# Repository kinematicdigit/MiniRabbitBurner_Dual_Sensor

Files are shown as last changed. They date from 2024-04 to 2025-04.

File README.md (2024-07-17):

# MiniRabbitBurner_Dual_Sensor (remixed Mini Stealthburner with Dual Sensors)

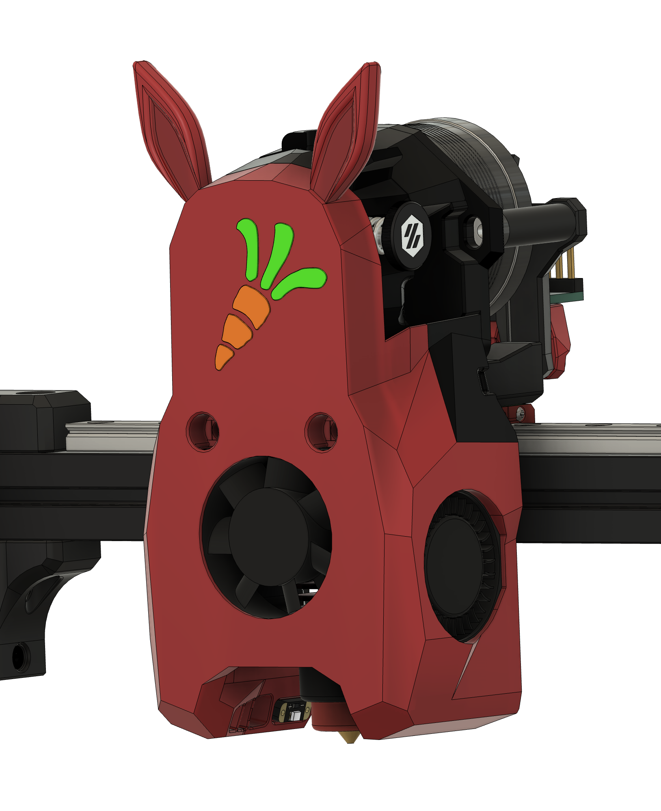
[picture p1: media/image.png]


Remix and optimized the Mini Stealthburner with dual sensors for use with ERCF. The filament path has been optimized for heavy load and unload duty cycles. Redesigned filament path for a more stable structure to handle the loading of heavily curved filaments and new wire channels for managing the new sensor wires.

BOM (in addition to standard Mini Stealthburner BOM)
(2)x Omron D2F-5L, D2F-01F, or D2F-01L Micro Switch
(1)x MR85ZZ bearings
(1)x 5.5 steel ball
(3) coloured 28AWG wires
(2)x M2x10mm SHCS or BHCS
(2) interconnects for your breakout board
(2) LED Sequins (optional)

Requires some soldering and well-tuned printer. Print the Swiss cheese calibration cube included in the repo.

Remixed/inspired from single switch version from:

https://www.printables.com/model/562384-voron-mini-stealthburner-ercf-filament-sensor

Redesigned from the original at:

https://github.com/VoronDesign/Voron-0/tree/Voron0.2r1/STLs

Added klicky mount versions based on:

https://github.com/jlas1/Klicky-Probe/blob/main/Printers/Voron/v0/v0_STL/V0_2r1_Klicky_MiniSB_Cowling.stl

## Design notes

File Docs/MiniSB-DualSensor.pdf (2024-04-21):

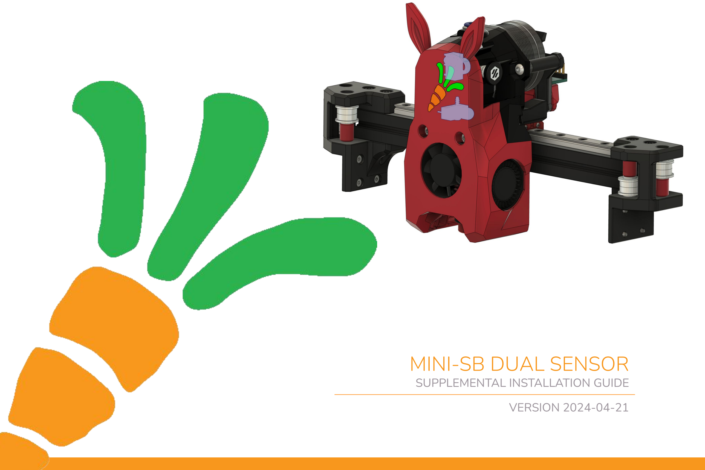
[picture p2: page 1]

VERSION 2024-04-21

# MINI-SB DUAL SENSOR

SUPPLEMENTAL INSTALLATION GUIDE

MINI STEALTHBURNER - DUAL SENSOR EDITION

2

This is a remix and optimized Mini Stealthburner with dual sensors for use with ERCF. The filament path has been optimized for heavy load and unload duty cycles. Redesigned filament path for a more stable structure to handle the loading of heavily curved filaments and new wire channels for managing the new sensor wires.
BOM (in addition to standard Mini Stealthburner BOM)
(2)x Omron D2F-5L, D2F-01F, or D2F-01L Micro Switch
(1)x MR85ZZ bearings
(1)x 5.5 steel ball (3) coloured 28AWG wires
(2)x M2x10mm SHCS or BHCS
(2) interconnects for your breakout board

Requires some soldering and well-tuned printer. Print the Swiss cheese calibration cube included in the repo. Please refer to the original Mini Stealthburner guide found in the Doc folder of the GitHub repository. I did not include every toolhead from the original repository, but if you are looking for a specific one, please request it and I can make an adjustment for it. I included the most popular heads in this current edition.

Remixed/inspired from single switch version from: https://www.printables.com/model/562384-voron-mini-stealthburner-ercf-filament-sensor

Redesigned from the original at: https://github.com/VoronDesign/Voron-0/tree/Voron0.2r1/STLs

2

INTRODUCTION

### GENERAL INFO

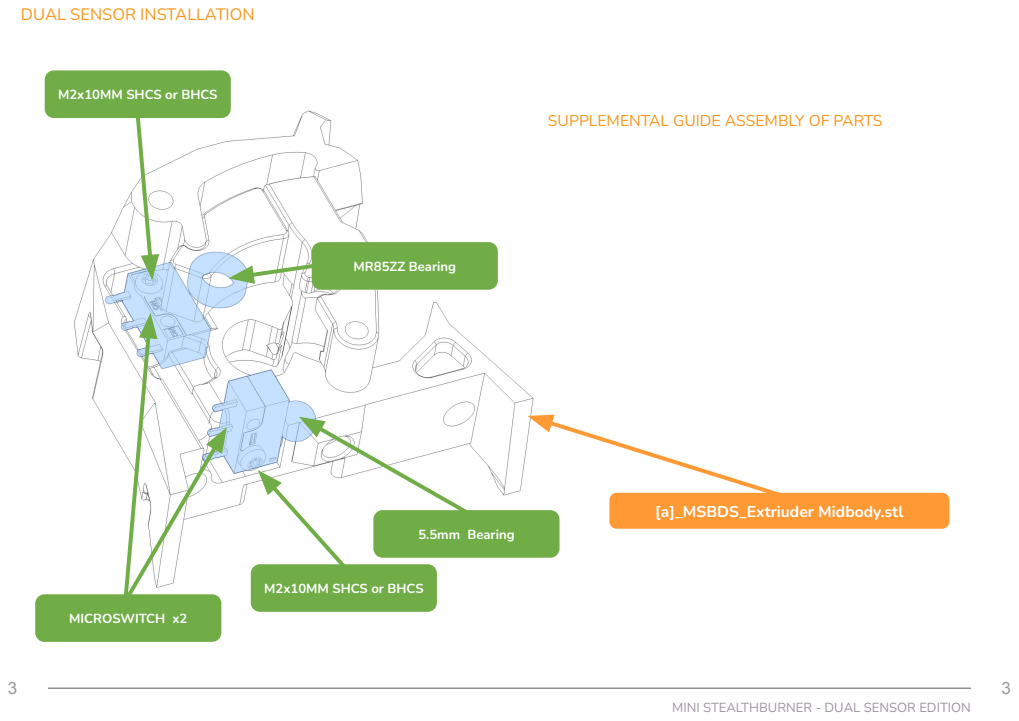
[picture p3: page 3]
MR85ZZ Bearing; [a]_MSBDS_Extriuder Midbody.stl; 5.5mm Bearing; MICROSWITCH x2

DUAL SENSOR INSTALLATION

M2x10MM SHCS or BHCS

SUPPLEMENTAL GUIDE ASSEMBLY OF PARTS

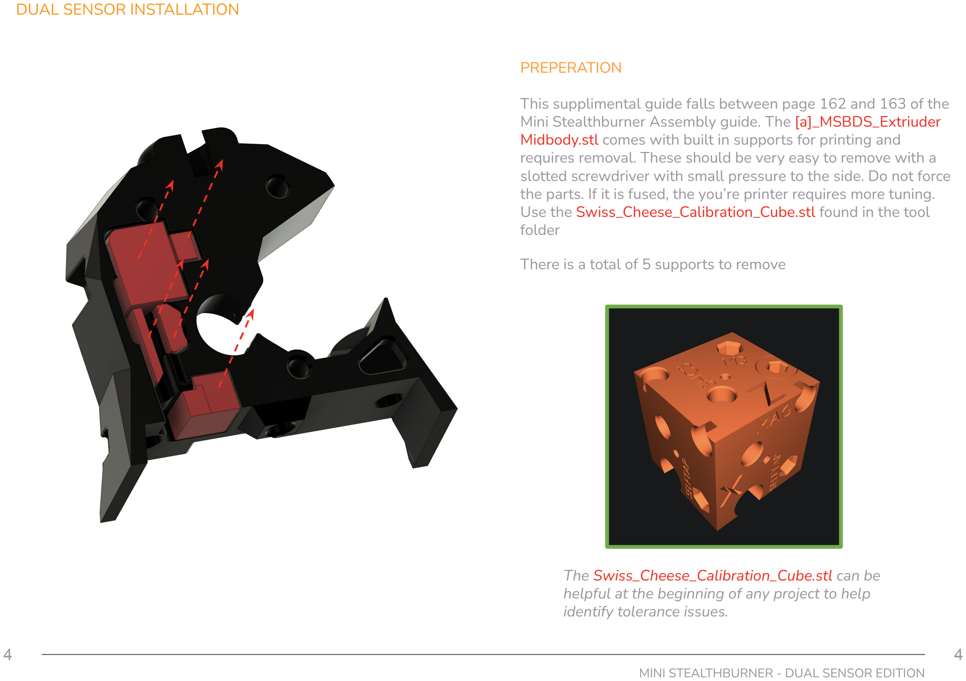
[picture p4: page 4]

DUAL SENSOR INSTALLATION

PREPERATION

This supplimental guide falls between page 162 and 163 of the Mini Stealthburner Assembly guide. The [a]_MSBDS_Extriuder Midbody.stl comes with built in supports for printing and requires removal. These should be very easy to remove with a slotted screwdriver with small pressure to the side. Do not force the parts. If it is fused, the you’re printer requires more tuning. Use the Swiss_Cheese_Calibration_Cube.stl found in the tool folder

There is a total of 5 supports to remove

The Swiss_Cheese_Calibration_Cube.stl can be helpful at the beginning of any project to help identify tolerance issues.

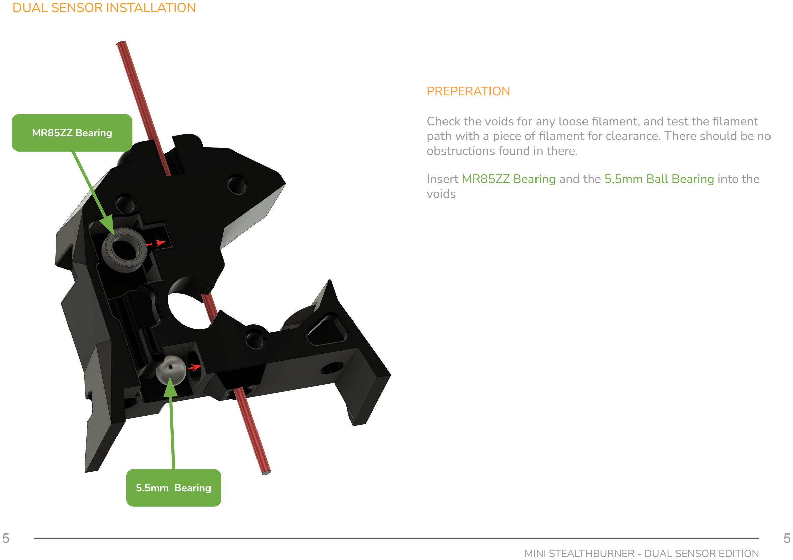
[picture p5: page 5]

DUAL SENSOR INSTALLATION

PREPERATION

Check the voids for any loose filament, and test the filament path with a piece of filament for clearance. There should be no obstructions found in there.

Insert MR85ZZ Bearing and the 5,5mm Ball Bearing into the voids

MR85ZZ Bearing

5.5mm Bearing

DUAL SENSOR INSTALLATION

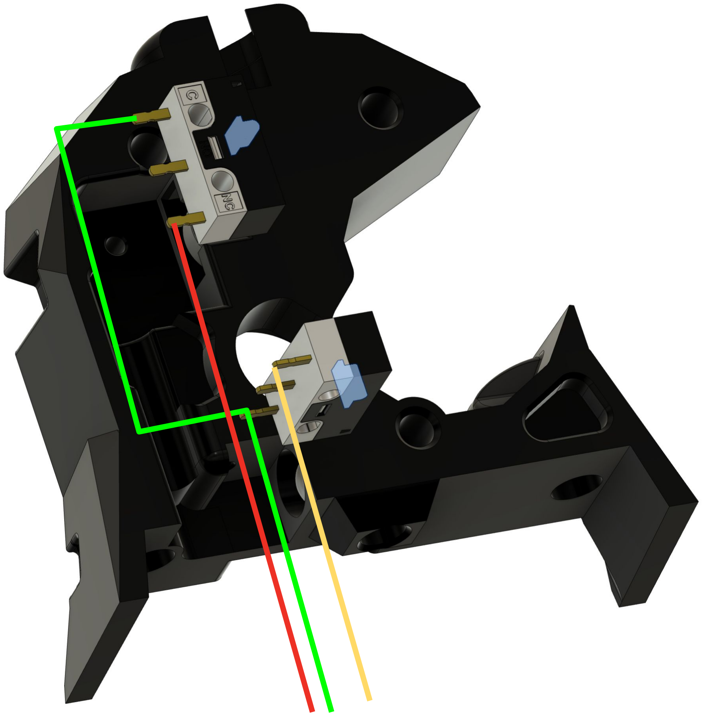
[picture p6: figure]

WIRING

Please note the plunger orientations for the switches. For the entry sensor, the plunger should be located towards the entry, while the toolhead sensor should be facing closest to the body.

Solder the two common leads together then solder two separate wires for the NC connector. Use three different colour wires to identify it later. Give plenty of length to trim when you wire.

You may use hotglue to protect the solder joints,

DUAL SENSOR INSTALLATION

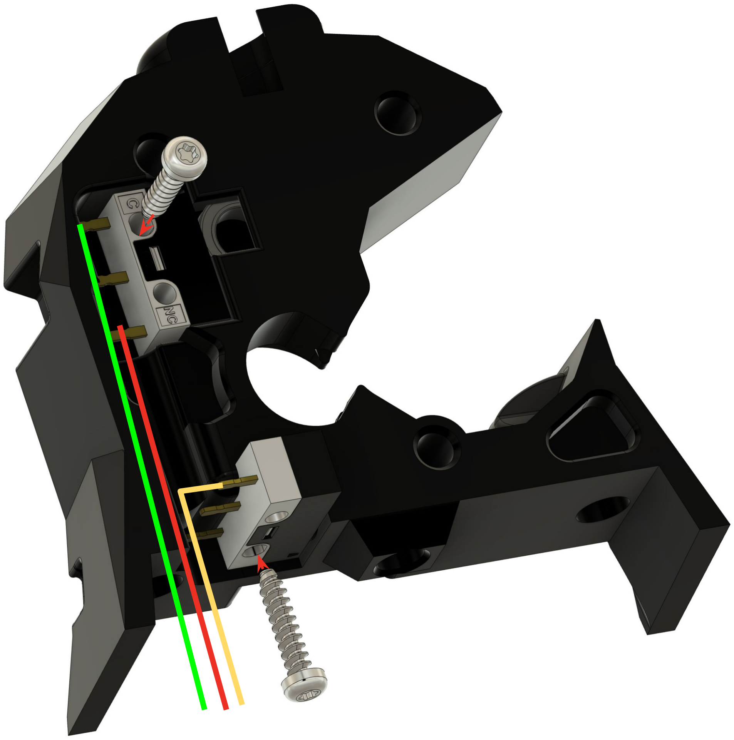
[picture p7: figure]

WIRING

Put wires into wire management channels, and screw down switches with one M2x10MM SHCS or BHCS per switch as illustrated.

DUAL SENSOR INSTALLATION

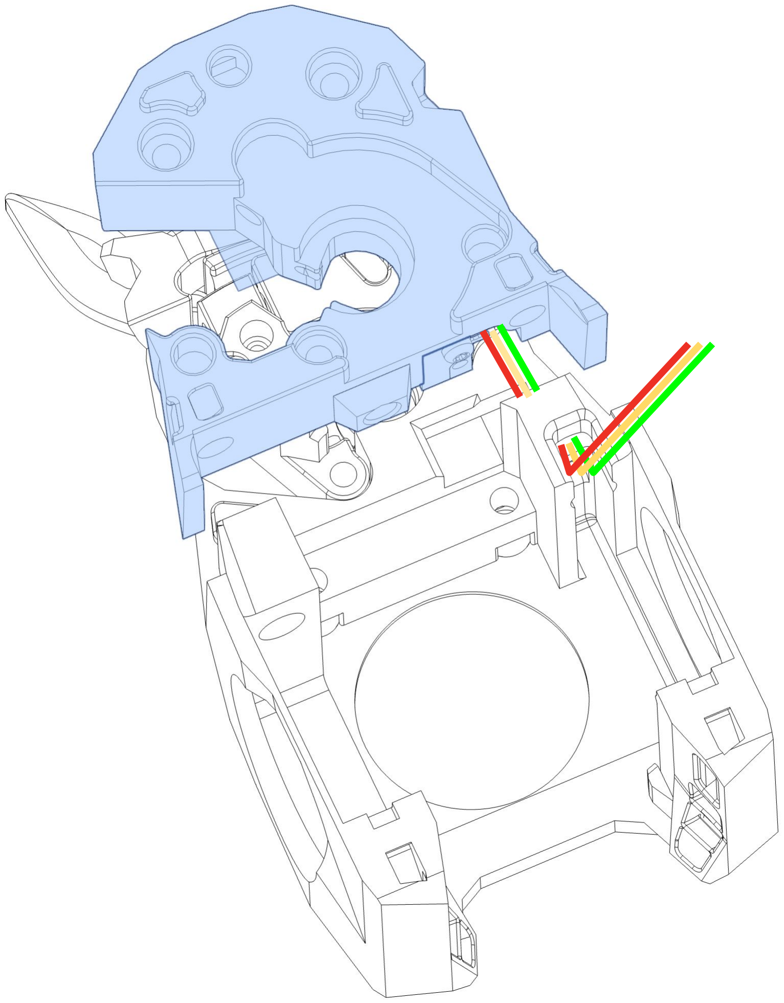
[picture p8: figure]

INSERT MID-BODY

As you insert the midbody into the cowl, route the wires through the channel on the side above the fan bay. Pull wires bundles through and position the midbody in place, careful to not pinch the wires as you do so.

Refer back to Mini Stealthburner assembly for final assembly.

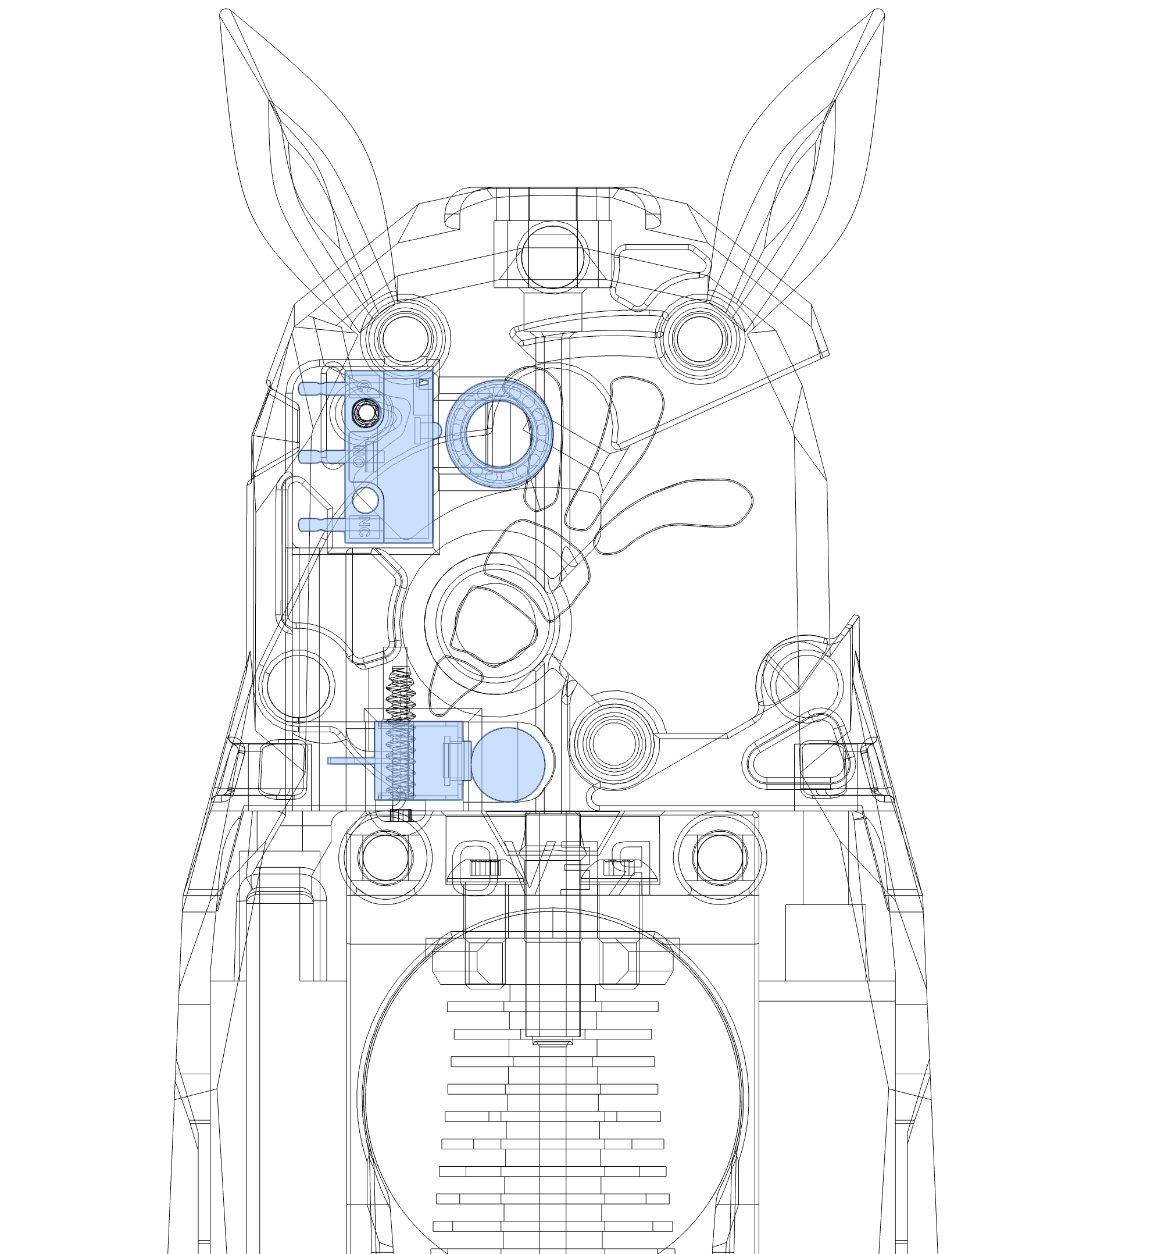
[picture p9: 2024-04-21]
media/linedrawing.png

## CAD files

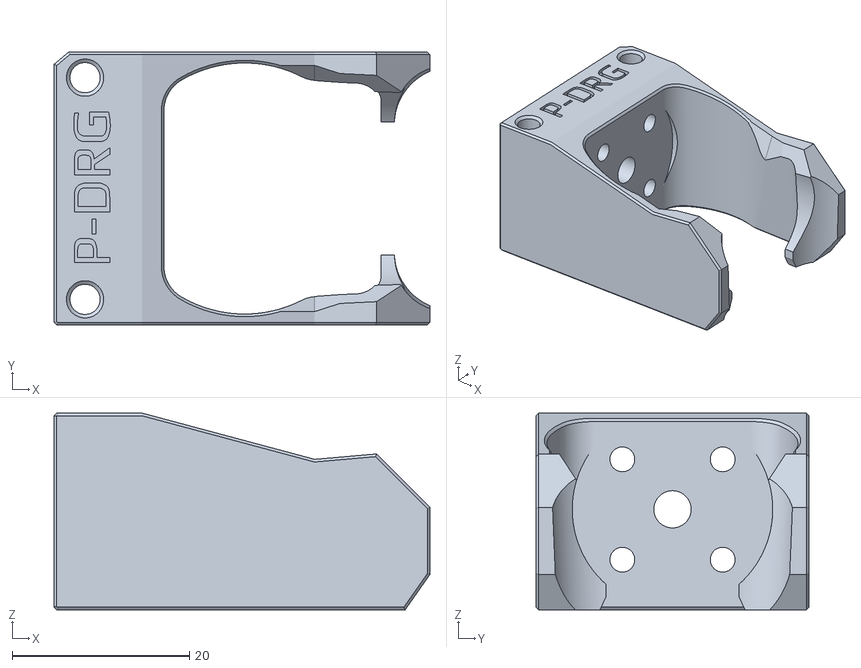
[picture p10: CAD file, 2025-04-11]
Hotend_mounts/[a]_MSBDS_Hotend_Mount_Dragon_x1.stl
42.4 x 30.8 x 22.2

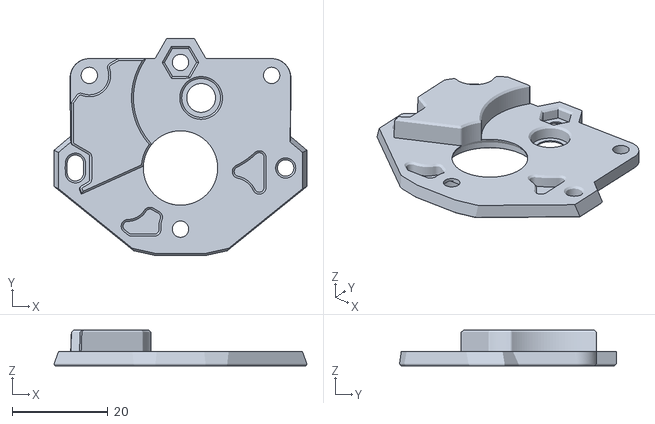
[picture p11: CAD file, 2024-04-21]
STLS/[a]_MiniSB_Motor_Plate_x1.stl
52.7 x 45.2 x 7.40

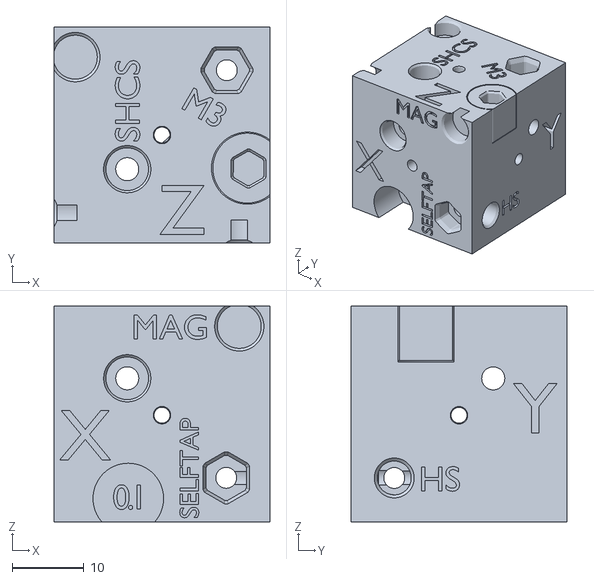
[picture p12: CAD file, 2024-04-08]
Tools/Swiss-Cheese-Calibration-Cube.stl
30.0 x 30.0 x 30.0

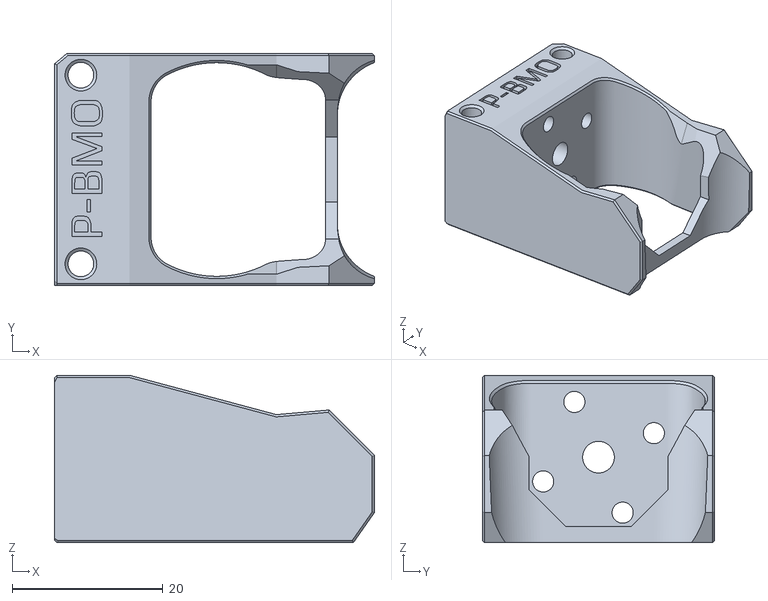
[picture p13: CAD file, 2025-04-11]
Hotend_mounts/[a]_MSBDS_Hotend_Mount_Dragonfly_BMO_x1.stl
42.4 x 30.8 x 22.2

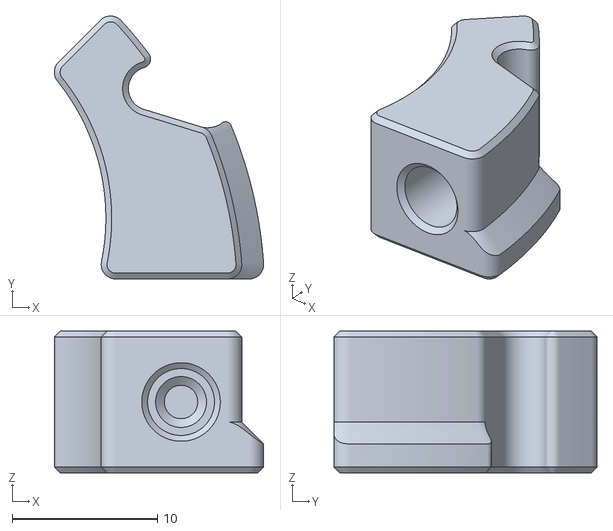
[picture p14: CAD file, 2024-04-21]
STLS/[a]_Shuttle_x1.stl
14.4 x 18.1 x 9.75

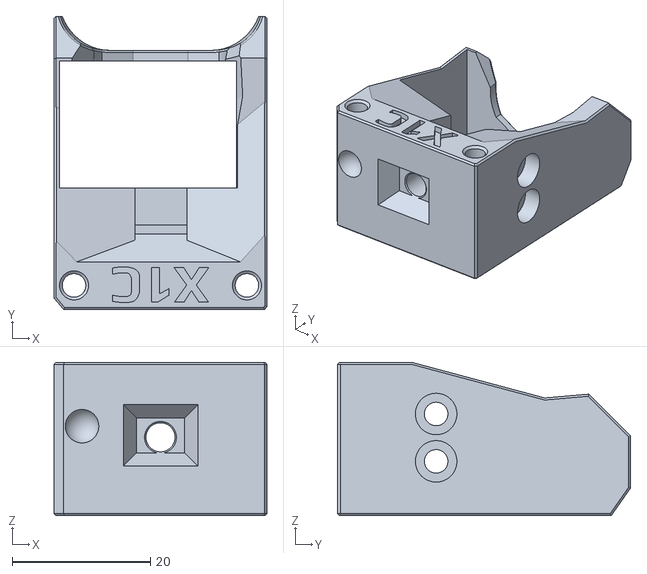
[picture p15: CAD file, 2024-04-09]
Hotend_mounts/[a]_MSBDS_Hotend_Mount_Bambu_X1C_x1.stl
30.8 x 42.4 x 22.2

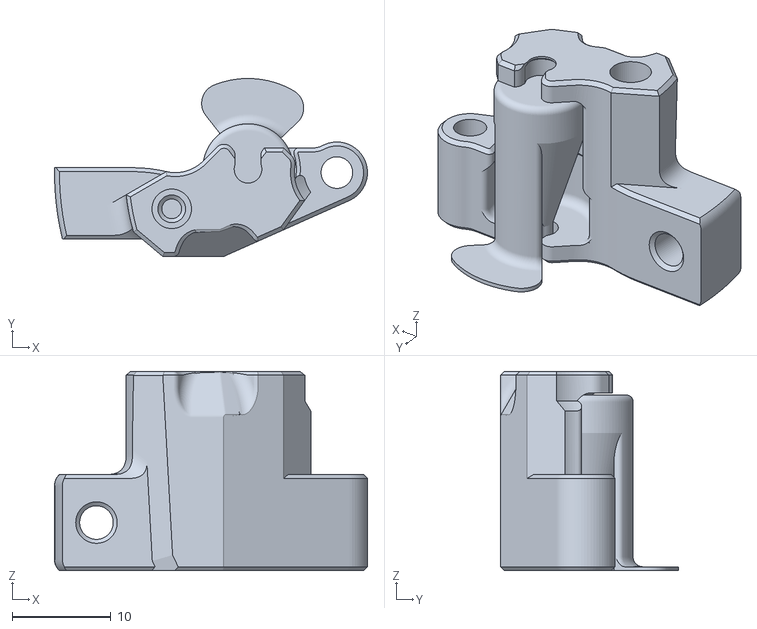
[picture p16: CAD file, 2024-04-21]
STLS/[a]_Guidler_x1.STL
31.7 x 18.0 x 20.2

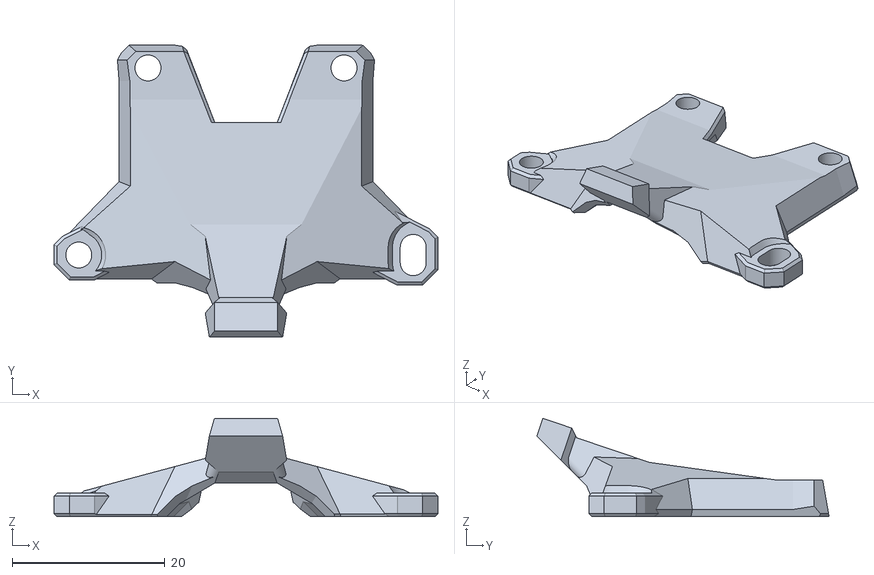
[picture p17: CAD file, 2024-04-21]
STLS/Strain_Relief_Body_x1.stl
50.3 x 38.3 x 12.9

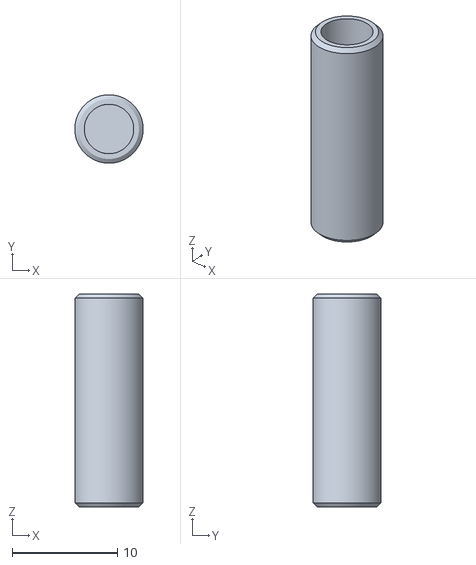
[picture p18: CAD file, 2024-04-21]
STLS/Strain_Relief_Spacer_x2.stl
6.50 x 6.50 x 20.2

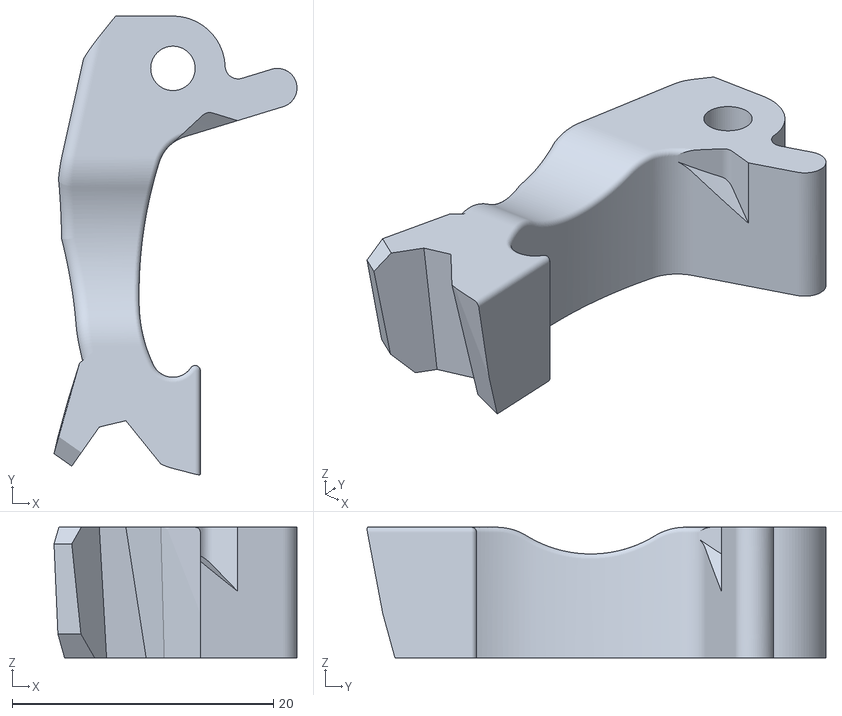
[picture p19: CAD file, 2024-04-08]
STLS/[a]_MSBDS_Latch_x1.stl
18.6 x 35.1 x 10.0

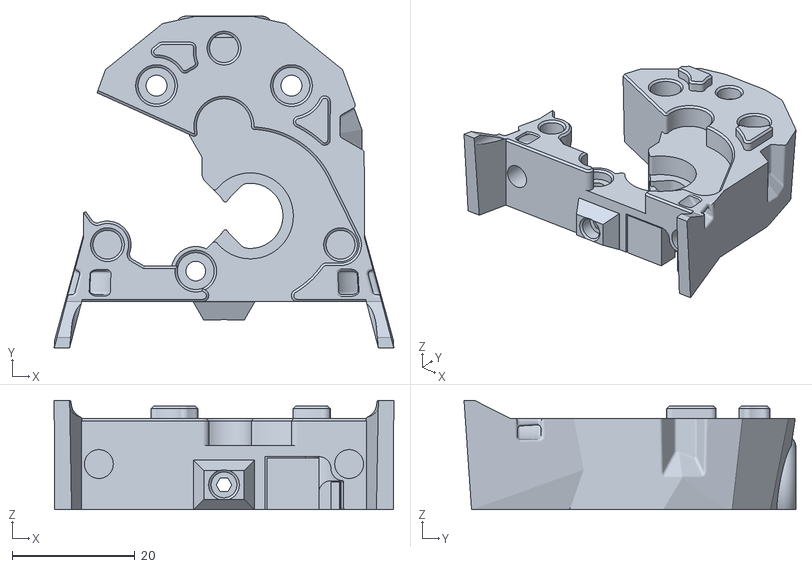
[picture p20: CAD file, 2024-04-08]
STLS/[a]_MSBDS_Extriuder Midbody.stl
55.4 x 54.1 x 17.8

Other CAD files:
Hotend_mounts/[a]_MSBDS_Hotend_Mount_Revo_Voron_x1.stl

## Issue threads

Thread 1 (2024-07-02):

STL for front without ears but with klicky

Smaefer, 2024-07-02:
Hi I wonder if it would be possible to add a stl for the front with the klicky like the step but without the ears hope that’s the right way to ask.
Thx

Closed 2024-07-11.

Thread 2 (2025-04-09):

Dragon Mount missing countersink for the screw head.

askmewhy25, 2025-04-09:
Hello. I am completing my ERCF 2.5 and found this mod for the Mini SB with sensor. I am using a Dragon Hotend and installing the MRB, but the screw for the Dragon mount is misaligned.  The Bambu and Revo mounts have countersunk holes, while the Dragon and Dragonfly mounts do not. Please update the mount. Thank you.

Closed 2025-04-11.

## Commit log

2024-04-08 Initial Release with Revo Toolhead mount
    [[a]_MSBDS_Extriuder Midbody.stl, [a]_MSBDS_Hotend_Mount_Revo_Voron_x1.stl, [a]_MSBDS_Latch_x1.stl]
2024-04-08 Update Media and Calibration Cube
    [Swiss-Cheese-Calibration-Cube.stl]
2024-04-09 Adjustments made and adding X1C Mount
    [MSBDS_X1C_Mount.stl, [a]_MSBDS_Hotend_Mount_Revo_Bambu_X1C_x1.stl]
2024-04-21 Reorganized and added a few more toolheads
    [Strain_Relief_Body_x1.stl, Strain_Relief_Spacer_x2.stl, Swiss-Cheese-Calibration-Cube.stl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]
2024-07-03 no ears klicky probe version
2024-07-17 Create ERCF_MiniSB-Dual-Sensors v3.step
    CAD Files for latest edition
2025-04-11 Clearance holes added to Dragon and Dragonfly mounts for M2 Screwhead
    [[a]_MSBDS_Hotend_Mount_Dragon_x1.stl, [a]_MSBDS_Hotend_Mount_Dragonfly_BMO_x1.stl]
